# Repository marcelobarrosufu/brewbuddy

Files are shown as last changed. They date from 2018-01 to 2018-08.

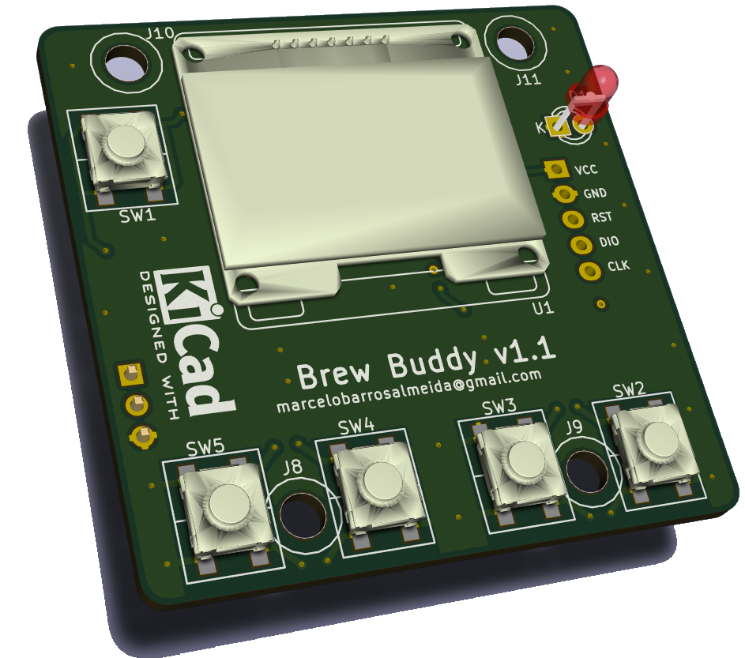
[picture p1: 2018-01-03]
brew_buddy_hardware/docs/f1.png

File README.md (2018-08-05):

# Description

BrewBuddy is a compact device for helping homebrewers in their exhausting task of converting malts, hops and yeasts into happiness.

It can be used as a simple thermometer, like any other analog thermometer found in the market but aggregating time control via stopwatch. As you know, time and temperature walk together when brewing a nice beer.

Although BrewBuddy is not a controller, you can program your recipe using a step mash strategy. BrewBuddy will blink a led when an step is finished, indicating that you can heat the mosture again.

When boiling, it is very easy to program your hop additions, waiting for a BrewBuddy indication. Smartphones or additional devices are not required anymore!

BrewBuddy is powered by a regular CR2032 battery, running for 20h! Menus and configurations are simple and intuitive, you will learn all function in minutes.

You can program up to 10 steps/hop additions (time) and the last setup is automatically saved in non volatile memory.

Some videos:

 - https://youtu.be/tlFAVe8KUfs
 - https://youtu.be/ZO_FSPlZCxY
 - https://youtu.be/FMSUGOILIN4
 - https://youtu.be/00Js_LpAEr8
 - https://youtu.be/yrWA2lQHpJ8

# Author

BrewBuddy was created from scracth by me, Marcelo Barros. I am an electrical engineer, professor and home brewer. After some bad experiences with uncalibrated analog thermometers I decided to create my own thermometer, agregating additional functionalities for mashing and boiling.

# Help Required

If you are a 3D expert and wanna help, please contact me. In the next week my new PCBs will arrive and I can ship  a complete and working board for those that want to develop or improve the current case.

# Compiling

 - Create a new workspace using System Worbenck for STM32 (SW4STM32). For instance,  <path>/brewbuddy
 - Go to brewbuddy directory and clone this repository
 - Starts SW4STM32 and import the project:   File->Import->General->Existing Projects into Workspace
 - In the dialog, please set:
    - Select root directory:  select your workspace directory, <path>/brewbuddy
    - Select the brew buddy project
    - Do not check the option "copy projects into workspace"
 - Before compiling, check optimization as "Optimize for Size (-Os)", under Properties->C/C++ Build->Tool Settings->MCU GCC Compiler->Optimization

# Firmware Notes

BrewBuddy firmware was built with low power requirements in mind, generating several actions:

 - The controller clock was reduced to 1MHz. Internal 8MHz clock (HSI) is used and PLL is disabled. 
 - I2C clock is only 100kHz (standard mode).
 - The main loop (see `main.c`) is only a _WFI (wake for interrupt) call, all code runs in interrupt mode:
   - Systick (1ms) timer is used to coordenate the periodic events (leds, display updates, ADC samplig and calibration). When some action is required, for instance a display update, it creates an event and sets SVD exception as pending. SVD is configured as a low priority exception, running only when other high priority interrupts are idle. This way we can ensure a better temporization for BrewBuddy.
  - Led modes were implemented as the amount of systick ticks for ON and OFF states. Using this strategy, the led processing is very light, taking few CPU time and energy.
  - Floating point is not used (less power and less flash requirements).
  
Some firmware notes:

  - As the battery voltage level is always falling I decided to calibrate the ADC periodically. DMA was not used to sampling the ADC values due the high cost in terms of flash usage. STM32 HAL takes some kBs of flash for DMA and a baremetal usage of DMA is required if we want to keep the flash usage low as possible. I need more time for this implementation. Or I need to use a microcontroller with bigger flash.
  - `bb_scr.c` is the main file for OLED screens. OLED screens are a machine state, in fact. Each screen is represented by a function (state) with the prototype `bb_scr_list_t bb_screen_function(bool first_time, bb_key_event_t *key)`, where:
    - `first_time`: it is used to indicate when we have a new screen to be presented or the same screen. Static text may be drawn in display using this flag, decreasing the amount of elements that need to be updated at each screen refresh.
    - `key`: if a key was pressed the information is here.
    - Remember: screens are implemented as a machine state (function based). So, you must return the next state when leaving the screen function. The list of states is given by the enumeration `bb_scr_list_t`. To include a new state, you must edit the macro `XMACRO_SCR_LIST`, adding a new state ID and a new function name, like `X(BB_SCR_NEW_OP_ID, bb_scr_new_op_boil)`. After, create a function for `bb_scr_new_op_boil` and implement the screen and your state changes based on the screen ID and keys pressed.
  - Step control is implemented in `ctrl.c`. Again, it is a machine state called at each 1s (see `ctrl_sm_run_1s()`). Given a proper initialization, steps can be followed by the states implemented in `ctrl.c`. 
  - All LMT86 handling was implemented in `lmt86.c`. Given the current temperature value (in ADC steps) and the amount of steps for a 2.5V reference, the real temperature (in degrees) is calculate (see `lmt86_conv_temp_1d()`). As we do not use floating point, conversion is based on a mV x degrees table (provided by datasheet). A simple interpolation is performed when the current value is not in the table. The temperature value is multiplied by ten for a minimum precision in integer operations.
  - If you want to change fonts, check the file `ssd1306_fonts.c`. We are using a small 7x5 font due to flash limits but it is possible to create bigger fonts and better presentation. The SSD1306 driver is minimal as well, a stripped/modified version of original driver provided by stm32f4-discovery.net. 
  - In `persist.c` you can find the default value for persistence and the routines to save / restore values from flash. A CRC is provided to check data integrity. The last flash sector (1kB) is used for data storage.
  
  At this moment, we do not have flash for anything else, even compiling for release and using size optimization:

| Flash | RAM (data+bss) |
| --- | --- |
| 15092 of 15360 bytes (98.3%) | 1200 of 4096 bytes (29.3%) |

# Adding localization support 

Some steps to add support for a new language:

  - Create a copy of `bb_locale_ENUS.h` and modify the suffix using a combination of [ISO-639 Language Codes and ISO ISO-3166 Country Codes](https://docs.oracle.com/cd/E13214_01/wli/docs92/xref/xqisocodes.html). For instance, you can use `bb_locale_ESCL.h` for Spanish and Chile.
  - Change the define `BB_DEFAULT_LOCALE` inside `bb_locale.h` (use your localization file name).
  - Translate the file contents. 
  - In special, for units, change `BB_TEMP_UNIT_IS_CELSIUS` and `BB_TEMP_UNIT_LABEL` for your corresponding temperature unit (0 and 'F' for Fahrenheit and 1 and 'C' for Celsius).

# CAD Files

Please, install KiCAD for opening schematics and PCB.

# TODO

 - When followings steps, make possible to go to next step without waiting the heating phase (just pressing RIGHT key)
 - Calibration menu
 - Setup menu, for temperatue and language
 - Change the microcontroller for more flash space (required for additional menus). STM32F030K6 or STM32F031F6 are possible options. The second one is more expensive but pin compatible.
 - Read internal temperature (for protection or calibration).
 - Low battery indication at startup.

# Licensing

BrewBuddy by Marcelo Barros de Almeida is licensed under a Creative Commons Attribution-NonCommercial-ShareAlike 4.0 International License.
If you want to create a commercial device based on BrewBuddy, please contact me for other licenses and prices.

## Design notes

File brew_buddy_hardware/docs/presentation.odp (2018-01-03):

## BrewBuddy: Overview

Author : Marcelo Barros de Almeida

Email : marcelobarrosalmeida@gmail.com

Project: https://hackaday.io/project/28667-brewbuddy

Code : https://github.com/marcelobarrosalmeida/brewbuddy

## BrewBuddy: Thermometer

Author : Marcelo Barros de Almeida

Email : marcelobarrosalmeida@gmail.com

Project: https://hackaday.io/project/28667-brewbuddy

Code : https://github.com/marcelobarrosalmeida/brewbuddy

## BrewBuddy: Moisture

Author : Marcelo Barros de Almeida

Email : marcelobarrosalmeida@gmail.com

Project: https://hackaday.io/project/28667-brewbuddy

Code : https://github.com/marcelobarrosalmeida/brewbuddy

## BrewBuddy: Boiling/Hoping

Author : Marcelo Barros de Almeida

Email : marcelobarrosalmeida@gmail.com

Project: https://hackaday.io/project/28667-brewbuddy

Code : https://github.com/marcelobarrosalmeida/brewbuddy

## What is BrewBuddy ?

  BrewBuddy is a compact device for helping homebrewers in their exhausting task of converting malts, hops and yeasts into happiness !

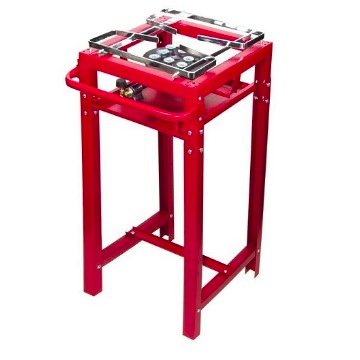
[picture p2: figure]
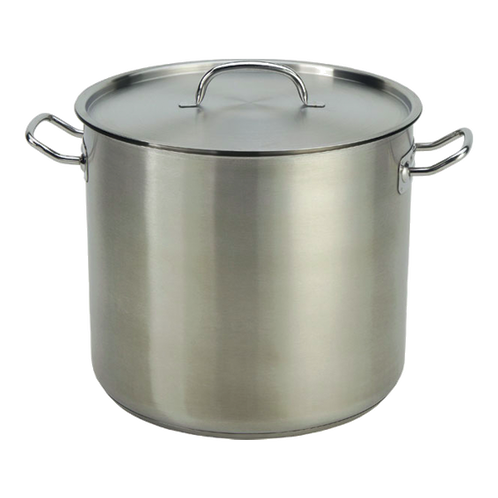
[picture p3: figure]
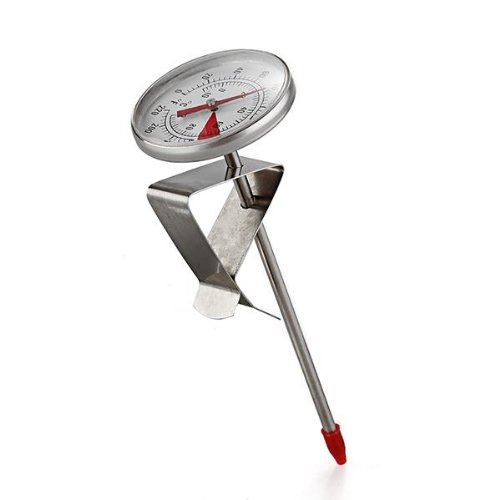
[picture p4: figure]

## BrewBuddy Functions

  - Thermometer: like an analog thermometer but aggregating time control via stopwatches (progressive and regressive).
  - Step mash: You can program your temperature steps and duration when mashing. BrewBuddy will blink a led when an step is finished.
  - Hop additions: When boiling, it is very easy to program your hop additions. Again, BrewBuddy will indicate when it occurs.

## BrewBuddy Functions

  - You can program up to ten mesh steps and ten hop additions.
  - Your last setup is automatically saved in non volatile memory.
  - BrewBuddy is powered by a CR2032 battery, working up to 20 hours.
  - Menus and configurations are simple and intuitive, you will learn all function in minutes.

## Main Components

  - Microcontrolled PCB using a low cost STM32F030F4
  - OLED Display 128x64
  - LMT86 analog temperature sensor
  - ADR5041BRTZ voltage reference (2.5V)
  - Stainless steel tube for temperature measurement
  - 3D housing under development

## BrewBuddy Navigation

On/off in a

single button

Indication

led

UP button

RIGHT button

DOWN button

LEFT button

## BrewBuddy Menu

BrewBuddy

starts here !

BOILING

Boiling programming (temperature and duration).

Hop additions programming (duration).

Boiling/hops follow up.

MOISTURE

Step programming (temperature and duration).

Steps follow up.

THERMOMETER

Temperature follow up and time measurements

## Demonstration Video

  For faster demonstration, usual timer (whose unit is minute) was replaced by a timer in seconds. Moreover, temperatures were simulated.
  ►Demonstration mode: turn BrewBuddy on with LEFT button pressed
  ►Factory init mode: turn BrewBuddy on with RIGHT button pressed


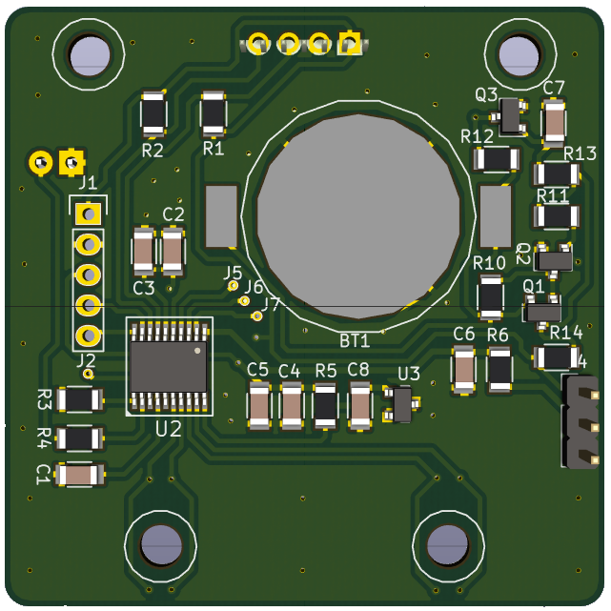
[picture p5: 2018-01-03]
brew_buddy_hardware/docs/f3.png

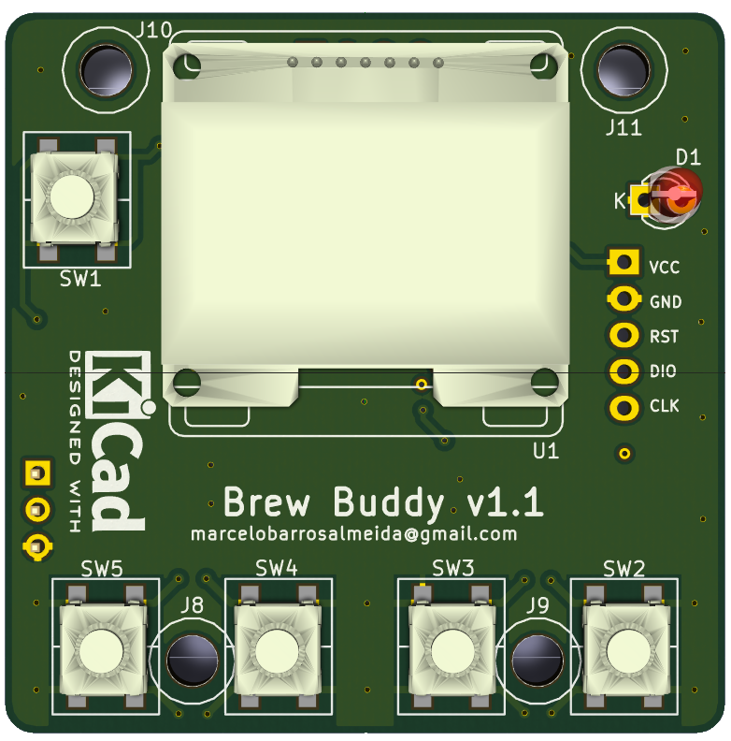
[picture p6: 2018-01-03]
brew_buddy_hardware/docs/f2.png

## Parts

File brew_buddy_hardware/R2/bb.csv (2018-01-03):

Source | /home/marcelo/Desktop/dados/bitbucket/beer_buddy_workspace/brew_buddy_hardware/R2/bb.sch
Kicad Rev | Eeschema 4.0.2+dfsg1-stable
Generated Date | Sex 29 Dez 2017 09:19:51 -02
Title | Beer Buddy
Company | Not Set
Revision | V1
Date Issue | 2017-10-16
Comment | All rights reserved
Comment | marcelobarrosalmeida@gmail.com
Comment | Marcelo Barros de Almeida
Reference | Value | Library | Library Ref
U2 | STM32F030F4 | bb | STM32F030F4
SW3 | SW_SPST | switches | SW_SPST
SW4 | SW_SPST | switches | SW_SPST
SW5 | SW_SPST | switches | SW_SPST
SW2 | SW_SPST | switches | SW_SPST
U1 | OLED-DISPLAY-I2C-128X64 | bb | OLED-DISPLAY-I2C-128X64
BT1 | CR2032 | device | Battery_Cell
J4 | Sensor | conn | Conn_01x03
C2 | 100nF | device | C_Small
C3 | 4.7uF | device | C_Small
C5 | 1uF | device | C_Small
R6 | 2K | device | R
R2 | 2K | device | R
R1 | 2K | device | R
C6 | 1uF | device | C_Small
R3 | 10K | device | R
R5 | 3K | device | R
C4 | 10nF | device | C_Small
D1 | LED | device | LED
R4 | 330R | device | R
J1 | JTAG | conn | Conn_01x05
C1 | 100nF | device | C_Small
J5 | PA7 | conn | Conn_01x01
J6 | PA6 | conn | Conn_01x01
J7 | PA5 | conn | Conn_01x01
J2 | PF1 | conn | Conn_01x01
U3 | ADR5041BRTZ | bb | ADR5041BRTZ
Q1 | PMV48XP (PMOS_GSD) | device | Q_PMOS_GSD
Q2 | PMV65UNER (NMOS_GSD) | device | Q_NMOS_GSD
Q3 | PMV65UNER (NMOS_GSD) | device | Q_NMOS_GSD
R10 | 100K | device | R
R11 | 100K | device | R
R13 | 1M | device | R
R12 | 100K | device | R
SW1 | SW_SPST | switches | SW_SPST
C7 | 470nF | device | C_Small
J8 | Drill | conn | Conn_01x01
J9 | Drill | conn | Conn_01x01
J10 | Drill | conn | Conn_01x01
J11 | Drill | conn | Conn_01x01
R14 | 0R | device | R
C8 | 100nF | device | C_Small

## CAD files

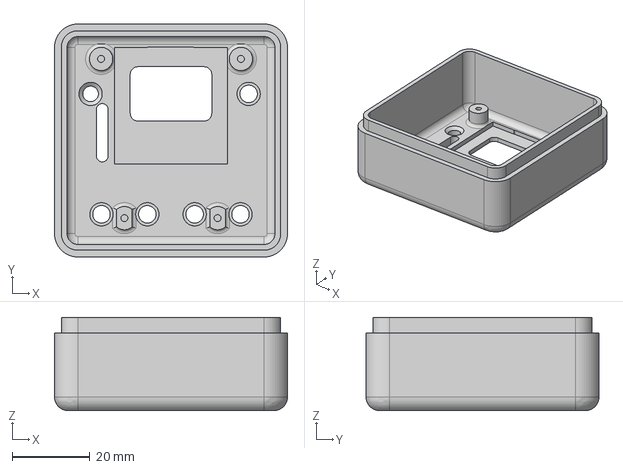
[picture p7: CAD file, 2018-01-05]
brew_buddy_case/Temp_Box_Front_New.step
60.0 x 60.0 x 24.0 mm

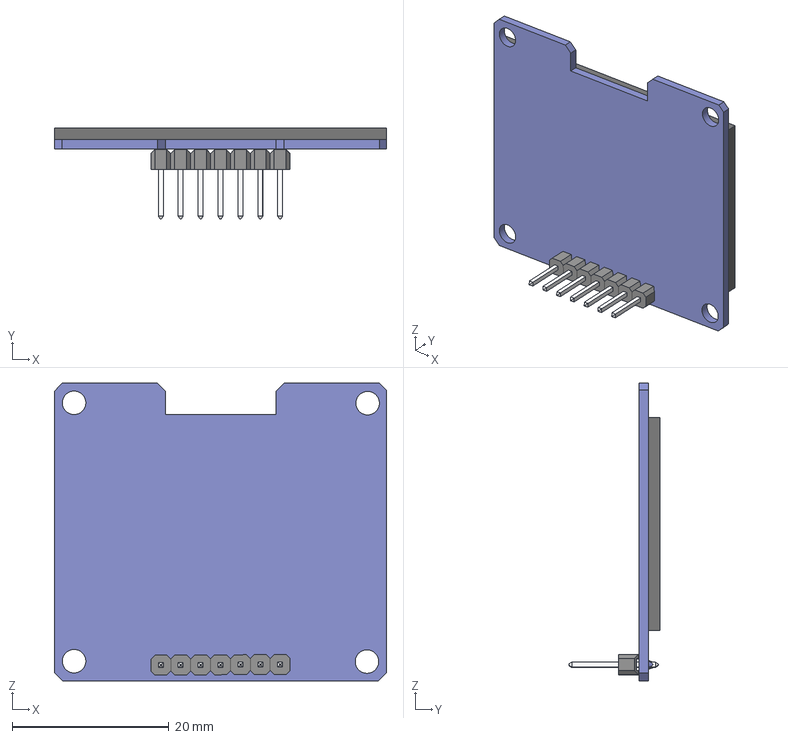
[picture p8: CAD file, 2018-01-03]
brew_buddy_hardware/3d/OLED Display 1.stp
42.4 x 11.7 x 38.0 mm

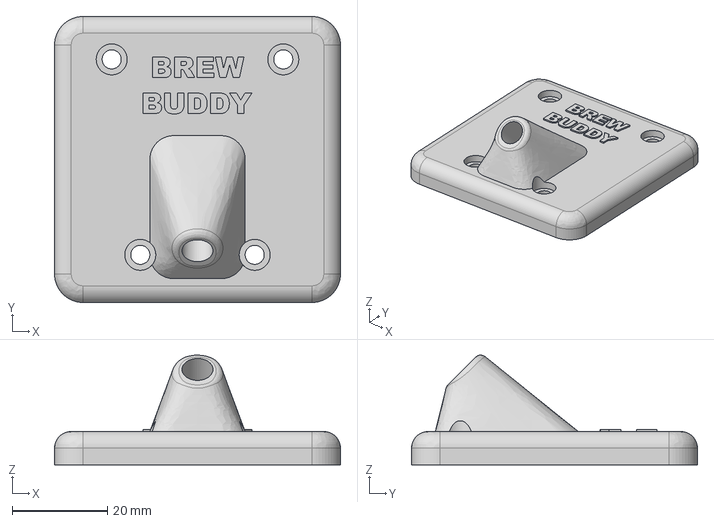
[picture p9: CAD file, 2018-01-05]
brew_buddy_case/Temp_Box_Back_New.step
60.0 x 60.0 x 23.0 mm

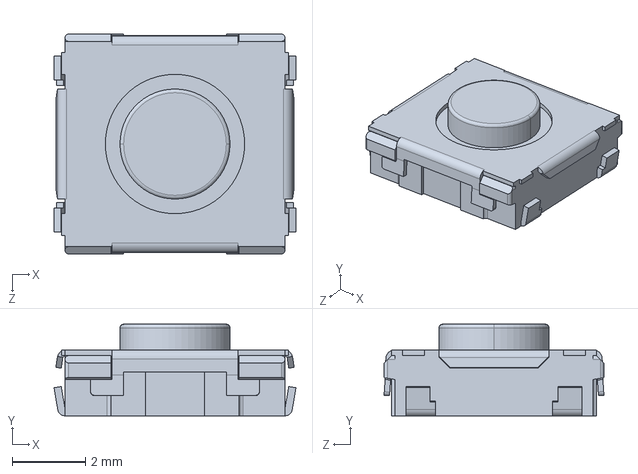
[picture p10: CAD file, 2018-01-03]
brew_buddy_hardware/3d/EVQQ2-BFKPUY-02W.STEP
6.60 x 2.50 x 6.00 mm

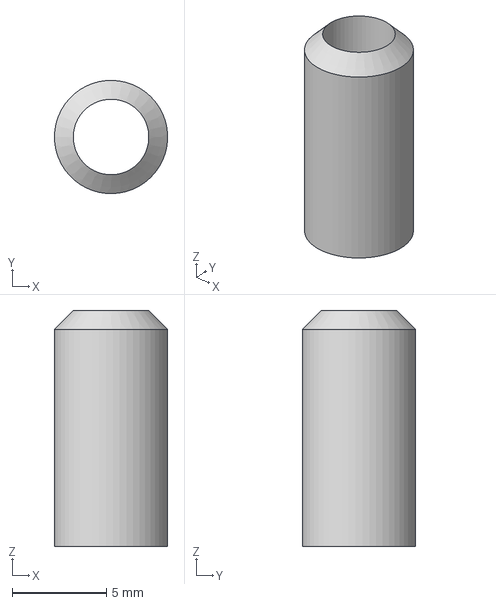
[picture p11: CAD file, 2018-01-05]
brew_buddy_case/Standoff_6X13.step
5.99 x 6.00 x 12.5 mm

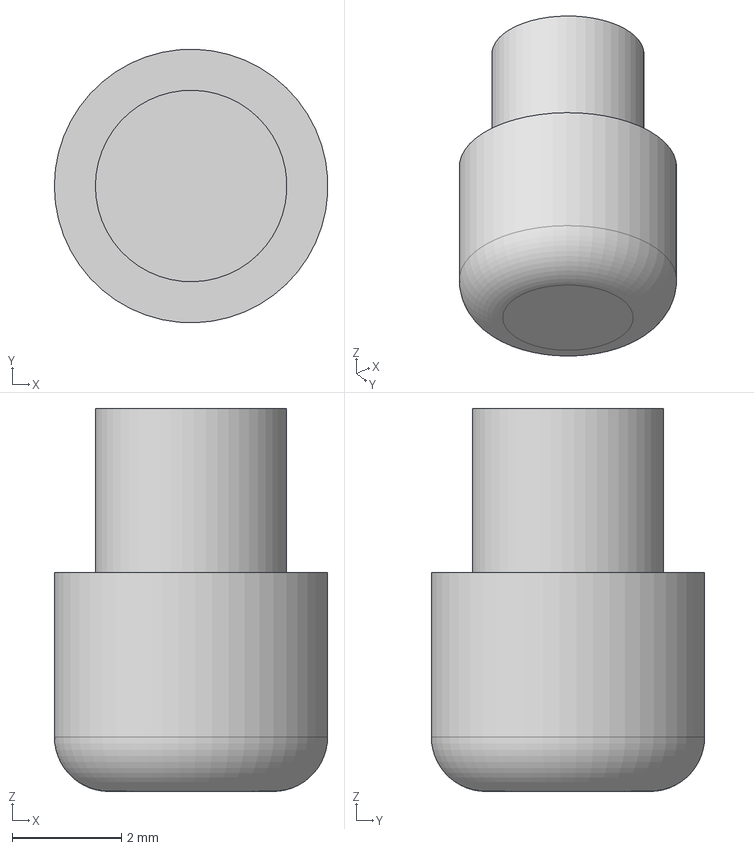
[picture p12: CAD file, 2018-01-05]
brew_buddy_case/Temp_Buttom_New.step
5.00 x 5.00 x 7.00 mm

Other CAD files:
brew_buddy_hardware/3d/OLED Display 2.stl
brew_buddy_case/Standoff_6X13.f3d
brew_buddy_case/Temp_Box_Back_New.f3d
brew_buddy_case/Temp_Box_Front_New.f3d
brew_buddy_case/Temp_Buttom_New.f3d
brew_buddy_hardware/3d/EVQQ2-BFKPUY-02W.stl
brew_buddy_hardware/3d/OLED Display 1.stl

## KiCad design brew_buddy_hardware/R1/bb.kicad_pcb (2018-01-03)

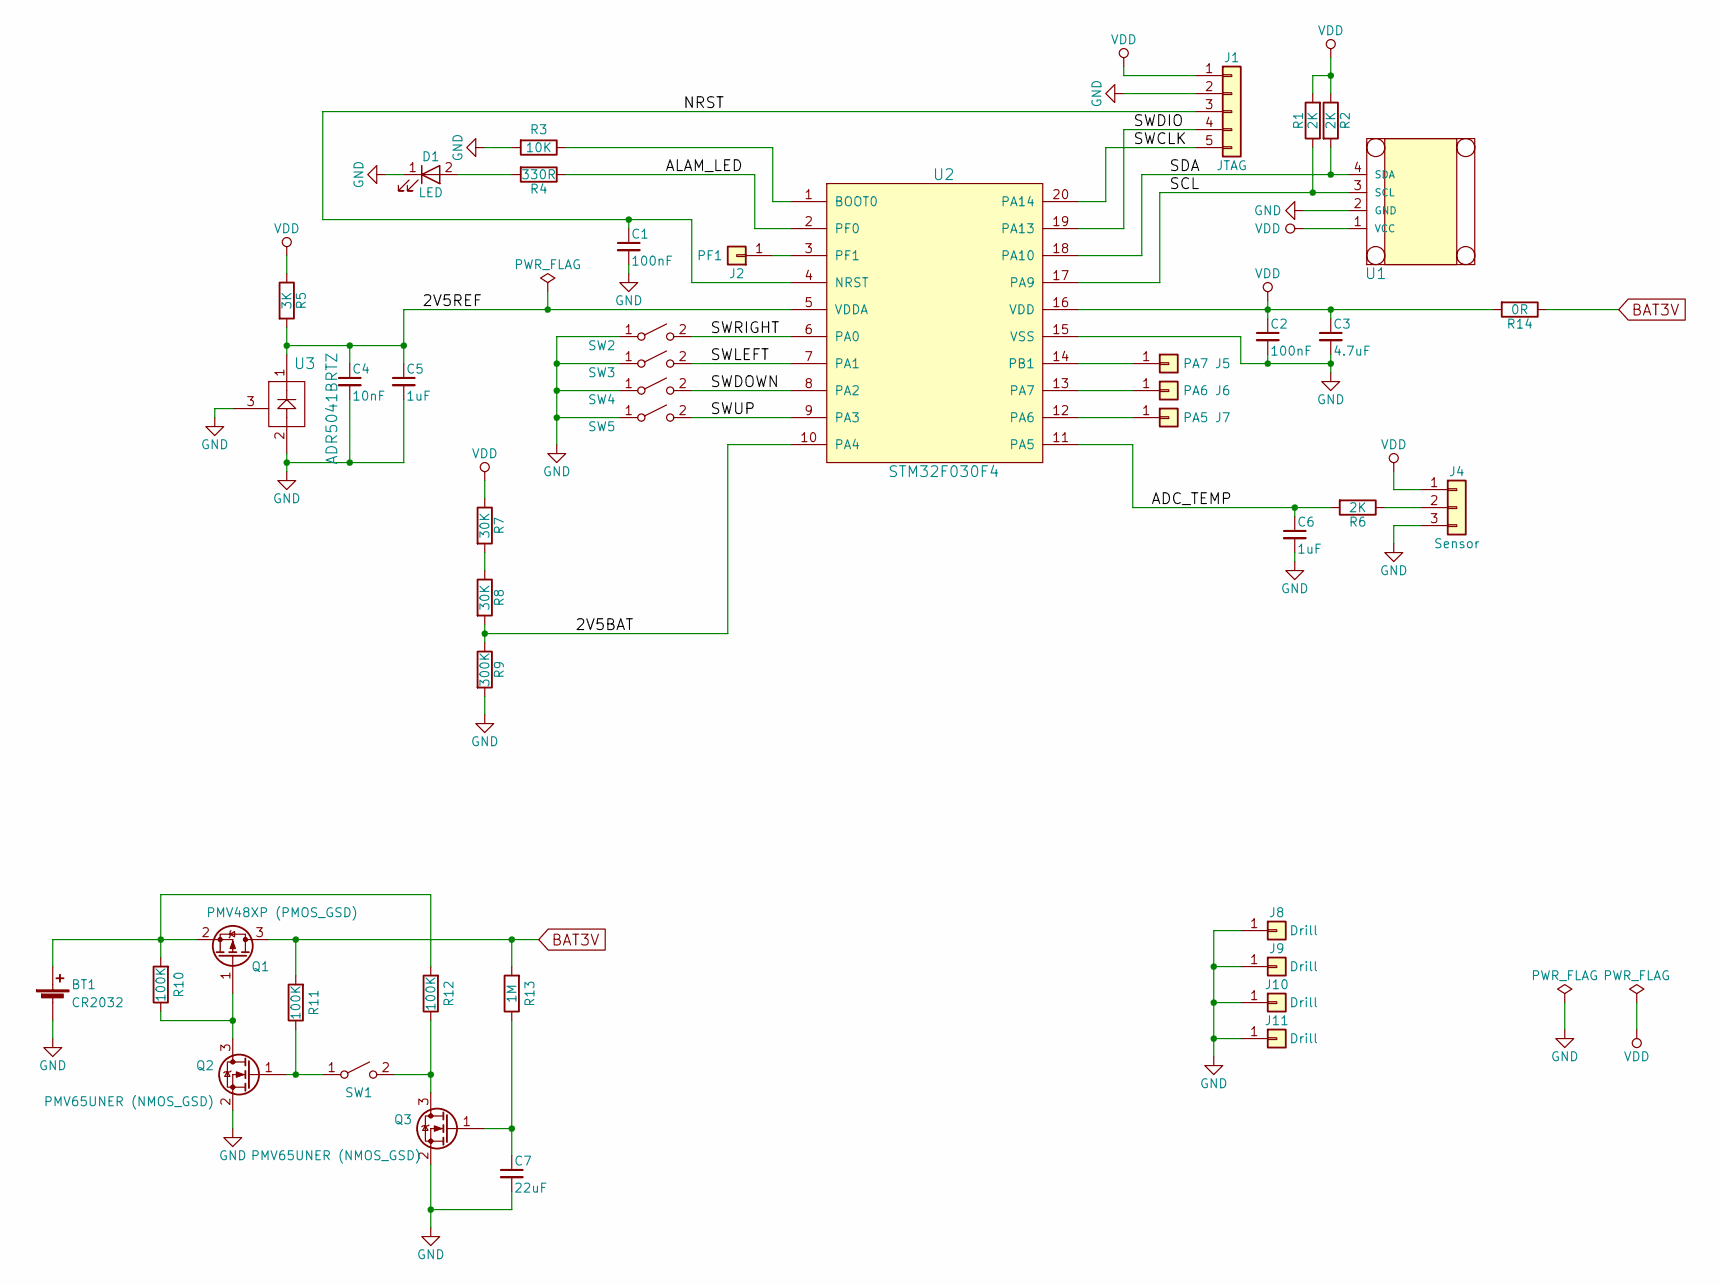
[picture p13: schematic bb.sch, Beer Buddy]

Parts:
BT1: CR2032; BAT-HLD-001-THM
C1, C2: 100nF; C_1206_CUSTOM
C3: 4.7uF; C_1206_CUSTOM
C4: 10nF; C_1206_CUSTOM
C5, C6: 1uF; C_1206_CUSTOM
C7: 22uF; C_1206_CUSTOM
D1: LED; LED-3MM
J1: JTAG; Pin_Header_Straight_1x05
J2: PF1; TEST-PIN
J4: Sensor; Pin_Header_Straight_1x03_Pitch2.54mm
J5: PA7; TEST-PIN
J6: PA6; TEST-PIN
J7: PA5; TEST-PIN
J8, J9, J10, J11: Drill; M3_Connector
Q1: PMV48XP (PMOS_GSD); SOT-23
Q2, Q3: PMV65UNER (NMOS_GSD); SOT-23
R1, R2, R6: 2K; R_1206_CUSTOM
R3: 10K; R_1206_CUSTOM
R4: 330R; R_1206_CUSTOM
R5: 3K; R_1206_CUSTOM
R7, R8: 30K; R_1206_CUSTOM
R9: 300K; R_1206_CUSTOM
R10, R11, R12: 100K; R_1206_CUSTOM
R13: 1M; R_1206_CUSTOM
R14: 0R; R_1206_CUSTOM
SW1, SW2, SW3, SW4, SW5: SW_SPST; EVQ-Q2B02W
U1: OLED-DISPLAY-I2C-128X64; DISPLAY-OLED
U2: STM32F030F4; TSOP-20-STM32F030F4
U3: ADR5041BRTZ; SOT-23

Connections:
/2V5BAT: R8.2, R9.1, U2.10 (PA4)
/2V5REF: C4.1, C5.1, R5.2, U2.5 (VDDA), U3.1
/ADC_TEMP: C6.1, R6.2, U2.11 (PA5)
/ALAM_LED: R4.1, U2.2 (PF0)
/NRST: C1.1, J1.3, U2.4 (NRST)
/SCL: R1.1, U1.3 (SCL), U2.17 (PA9)
/SDA: R2.2, U1.4 (SDA), U2.18 (PA10)
/SWCLK: J1.5, U2.20 (PA14)
/SWDIO: J1.4, U2.19 (PA13)
/SWDOWN: SW4.2 (B), U2.8 (PA2)
/SWLEFT: SW3.2 (B), U2.7 (PA1)
/SWRIGHT: SW2.2 (B), U2.6 (PA0)
/SWUP: SW5.2 (B), U2.9 (PA3)
BAT3V: Q1.3 (D), R11.2, R13.2, R14.1
GND: BT1.2 (-), C1.2, C2.2, C3.2, C4.2, C5.2, C6.2, C7.2, D1.1 (K), J1.2, J4.3, J8.1, J9.1, J10.1, J11.1, Q2.2 (S), Q3.2 (S), R3.2, R9.2, SW2.1 (A), SW3.1 (A), SW4.1 (A), SW5.1 (A), U1.2 (GND), U2.15 (VSS), U3.2, U3.3
unnamed: BT1.1 (+), Q1.2 (S), R10.2, R12.2
unnamed: C7.1, Q3.1 (G), R13.1
unnamed: D1.2 (A), R4.2
unnamed: J2.1, U2.3 (PF1)
unnamed: J4.2, R6.1
unnamed: J5.1, U2.14 (PB1)
unnamed: J6.1, U2.13 (PA7)
unnamed: J7.1, U2.12 (PA6)
unnamed: Q1.1 (G), Q2.3 (D), R10.1
unnamed: Q2.1 (G), R11.1, SW1.1 (A)
unnamed: Q3.3 (D), R12.1, SW1.2 (B)
unnamed: R3.1, U2.1 (BOOT0)
unnamed: R7.2, R8.1
VDD: C2.1, C3.1, J1.1, J4.1, R1.2, R2.1, R5.1, R7.1, R14.2, U1.1 (VCC), U2.16 (VDD)

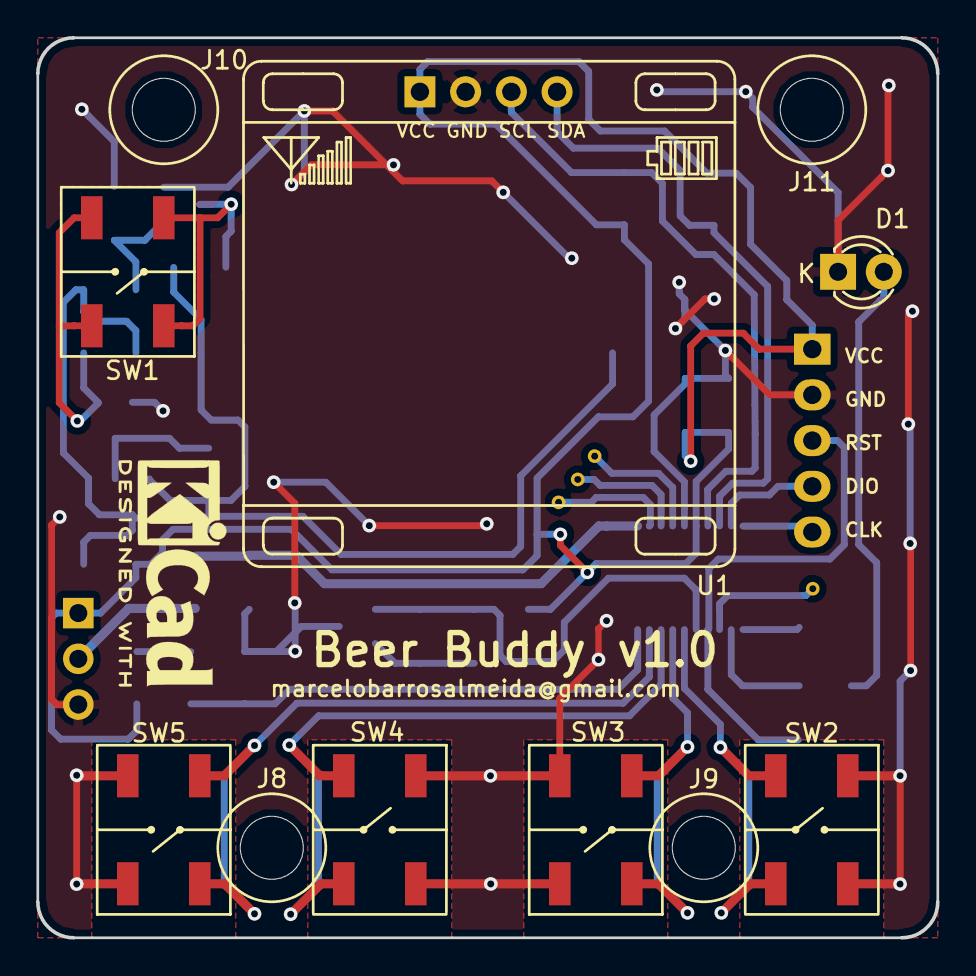
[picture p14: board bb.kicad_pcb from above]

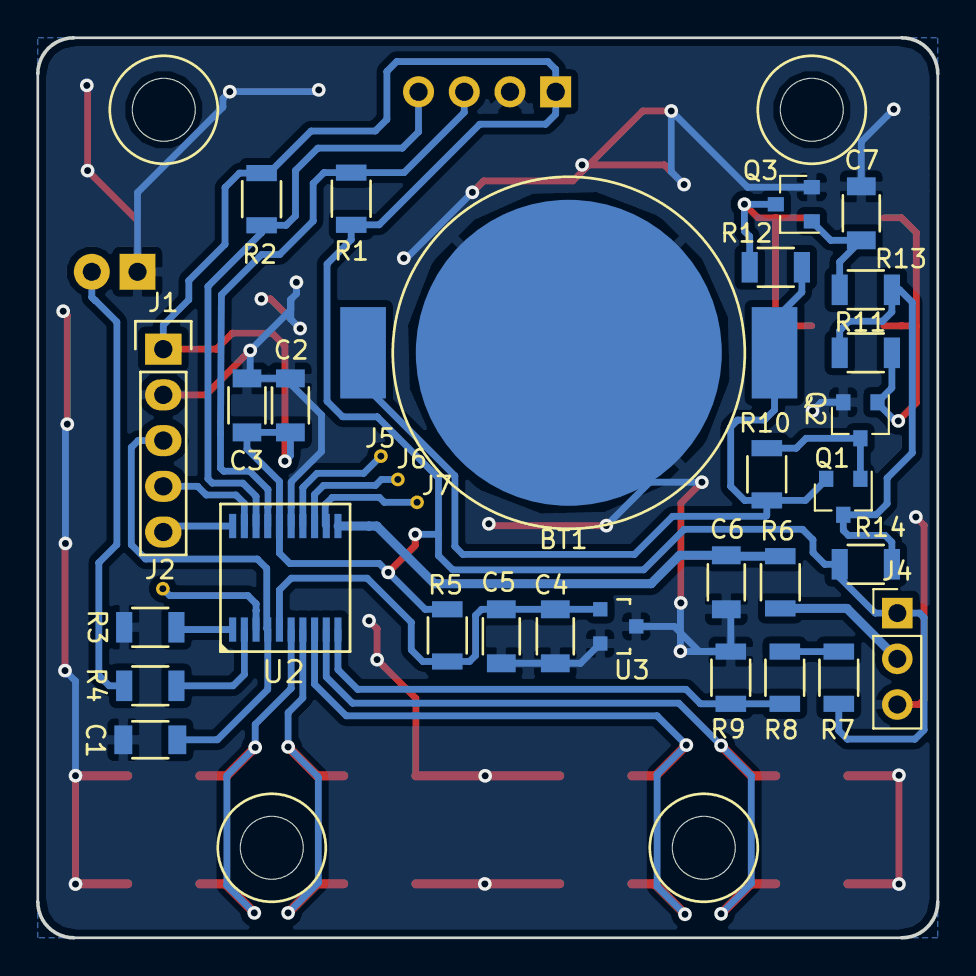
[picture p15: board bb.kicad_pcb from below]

Board: 2 copper layers, 50.0 x 50.0 mm, 44 parts (33 on the bottom side), 29 nets.

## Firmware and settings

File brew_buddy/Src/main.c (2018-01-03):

/*
  BrewBuddy by Marcelo Barros de Almeida is licensed under a
  Creative Commons Attribution-NonCommercial-ShareAlike 4.0 International License.

  For commercial usage, please contact the author via marcelobarrosalmeida@gmail.com
*/

/**
  ******************************************************************************
  * File Name          : main.c
  * Description        : Main program body
  ******************************************************************************
  ** This notice applies to any and all portions of this file
  * that are not between comment pairs USER CODE BEGIN and
  * USER CODE END. Other portions of this file, whether 
  * inserted by the user or by software development tools
  * are owned by their respective copyright owners.
  *
  * COPYRIGHT(c) 2017 STMicroelectronics
  *
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
  ******************************************************************************
  */

/* Includes ------------------------------------------------------------------*/
#include "main.h"
#include "stm32f0xx_hal.h"

/* USER CODE BEGIN Includes */
#include <stdbool.h>
#include <stdint.h>
#include "bb.h"
/* USER CODE END Includes */

ADC_HandleTypeDef hadc;

CRC_HandleTypeDef hcrc;

I2C_HandleTypeDef hi2c1;

IWDG_HandleTypeDef hiwdg;

/* USER CODE BEGIN PV */

/* USER CODE END PV */

void SystemClock_Config(void);
static void MX_GPIO_Init(void);
static void MX_I2C1_Init(void);
static void MX_ADC_Init(void);
static void MX_CRC_Init(void);
static void MX_IWDG_Init(void);

/* USER CODE BEGIN PFP */

/* USER CODE END PFP */

/* USER CODE BEGIN 0 */
void SystemClock_Config_Custom(void)
{
  uint32_t tickstart;

  __HAL_RCC_HSI_CALIBRATIONVALUE_ADJUST(16);
  __HAL_RCC_HSI14ADC_DISABLE();
  __HAL_RCC_HSI14_ENABLE();

  tickstart = HAL_GetTick();
  while(__HAL_RCC_GET_FLAG(RCC_FLAG_HSI14RDY) == RESET)
  {
    if((HAL_GetTick() - tickstart) > HSI14_TIMEOUT_VALUE)
      break;
  }

  __HAL_RCC_HSI14_CALIBRATIONVALUE_ADJUST(16);
  MODIFY_REG(RCC->CFGR, RCC_CFGR_HPRE, RCC_SYSCLK_DIV8);

  __HAL_RCC_SYSCLK_CONFIG(RCC_SYSCLKSOURCE_HSI);

  /* Get Start Tick */
  tickstart = HAL_GetTick();

  while (__HAL_RCC_GET_SYSCLK_SOURCE() != RCC_SYSCLKSOURCE_STATUS_HSI)
  {
    if((HAL_GetTick() - tickstart ) > CLOCKSWITCH_TIMEOUT_VALUE)
      break;
  }

  MODIFY_REG(RCC->CFGR, RCC_CFGR_PPRE, RCC_HCLK_DIV1);
  SystemCoreClock = HAL_RCC_GetSysClockFreq() >> AHBPrescTable[(RCC->CFGR & RCC_CFGR_HPRE)>> RCC_CFGR_HPRE_BITNUMBER];

  HAL_InitTick (TICK_INT_PRIORITY);

  __HAL_RCC_I2C1_CONFIG(RCC_I2C1CLKSOURCE_HSI);

    /**Configure the Systick interrupt time
    */
  HAL_SYSTICK_Config(HAL_RCC_GetHCLKFreq()/1000);

    /**Configure the Systick
    */
  HAL_SYSTICK_CLKSourceConfig(SYSTICK_CLKSOURCE_HCLK);

  /* SysTick_IRQn interrupt configuration */
  HAL_NVIC_SetPriority(SysTick_IRQn, 0, 0);
}

/* USER CODE END 0 */

int main(void)
{

  /* MCU Configuration----------------------------------------------------------*/

  /* Reset of all peripherals, Initializes the Flash interface and the Systick. */
  HAL_Init();

  /* USER CODE BEGIN Init */
#if 1
  SystemClock_Config_Custom();
#else
  /* USER CODE END Init */

  /* Configure the system clock */
  SystemClock_Config();

  /* USER CODE BEGIN SysInit */
#endif
  /* USER CODE END SysInit */

  /* Initialize all configured peripherals */
  MX_GPIO_Init();
  MX_I2C1_Init();
  MX_ADC_Init();
  MX_CRC_Init();
  MX_IWDG_Init();

  /* USER CODE BEGIN 2 */
  bb_init();
  /* USER CODE END 2 */

  /* Infinite loop */
  /* USER CODE BEGIN WHILE */
  while (1)
  {
	  __WFI();
	  HAL_IWDG_Refresh(&hiwdg);
  /* USER CODE END WHILE */

  /* USER CODE BEGIN 3 */

  }
  /* USER CODE END 3 */

}

/** System Clock Configuration
*/
void SystemClock_Config(void)
{

  RCC_OscInitTypeDef RCC_OscInitStruct;
  RCC_ClkInitTypeDef RCC_ClkInitStruct;
  RCC_PeriphCLKInitTypeDef PeriphClkInit;

    /**Initializes the CPU, AHB and APB busses clocks 
    */
  RCC_OscInitStruct.OscillatorType = RCC_OSCILLATORTYPE_HSI|RCC_OSCILLATORTYPE_HSI14
                              |RCC_OSCILLATORTYPE_LSI;
  RCC_OscInitStruct.HSIState = RCC_HSI_ON;
  RCC_OscInitStruct.HSI14State = RCC_HSI14_ON;
  RCC_OscInitStruct.HSICalibrationValue = 16;
  RCC_OscInitStruct.HSI14CalibrationValue = 16;
  RCC_OscInitStruct.LSIState = RCC_LSI_ON;
  RCC_OscInitStruct.PLL.PLLState = RCC_PLL_NONE;
  if (HAL_RCC_OscConfig(&RCC_OscInitStruct) != HAL_OK)
  {
    _Error_Handler(__FILE__, __LINE__);
  }

    /**Initializes the CPU, AHB and APB busses clocks 
    */
  RCC_ClkInitStruct.ClockType = RCC_CLOCKTYPE_HCLK|RCC_CLOCKTYPE_SYSCLK
                              |RCC_CLOCKTYPE_PCLK1;
  RCC_ClkInitStruct.SYSCLKSource = RCC_SYSCLKSOURCE_HSI;
  RCC_ClkInitStruct.AHBCLKDivider = RCC_SYSCLK_DIV8;
  RCC_ClkInitStruct.APB1CLKDivider = RCC_HCLK_DIV1;

  if (HAL_RCC_ClockConfig(&RCC_ClkInitStruct, FLASH_LATENCY_0) != HAL_OK)
  {
    _Error_Handler(__FILE__, __LINE__);
  }

  PeriphClkInit.PeriphClockSelection = RCC_PERIPHCLK_I2C1;
  PeriphClkInit.I2c1ClockSelection = RCC_I2C1CLKSOURCE_HSI;
  if (HAL_RCCEx_PeriphCLKConfig(&PeriphClkInit) != HAL_OK)
  {
    _Error_Handler(__FILE__, __LINE__);
  }

    /**Configure the Systick interrupt time 
    */
  HAL_SYSTICK_Config(HAL_RCC_GetHCLKFreq()/1000);

    /**Configure the Systick 
    */
  HAL_SYSTICK_CLKSourceConfig(SYSTICK_CLKSOURCE_HCLK);

  /* SysTick_IRQn interrupt configuration */
  HAL_NVIC_SetPriority(SysTick_IRQn, 0, 0);
}

/* ADC init function */
static void MX_ADC_Init(void)
{

  ADC_ChannelConfTypeDef sConfig;

    /**Configure the global features of the ADC (Clock, Resolution, Data Alignment and number of conversion) 
    */
  hadc.Instance = ADC1;
  hadc.Init.ClockPrescaler = ADC_CLOCK_ASYNC_DIV1;
  hadc.Init.Resolution = ADC_RESOLUTION_12B;
  hadc.Init.DataAlign = ADC_DATAALIGN_RIGHT;
  hadc.Init.ScanConvMode = ADC_SCAN_DIRECTION_FORWARD;
  hadc.Init.EOCSelection = ADC_EOC_SINGLE_CONV;
  hadc.Init.LowPowerAutoWait = ENABLE;
  hadc.Init.LowPowerAutoPowerOff = ENABLE;
  hadc.Init.ContinuousConvMode = DISABLE;
  hadc.Init.DiscontinuousConvMode = DISABLE;
  hadc.Init.ExternalTrigConv = ADC_SOFTWARE_START;
  hadc.Init.ExternalTrigConvEdge = ADC_EXTERNALTRIGCONVEDGE_NONE;
  hadc.Init.DMAContinuousRequests = DISABLE;
  hadc.Init.Overrun = ADC_OVR_DATA_PRESERVED;
  if (HAL_ADC_Init(&hadc) != HAL_OK)
  {
    _Error_Handler(__FILE__, __LINE__);
  }

    /**Configure for the selected ADC regular channel to be converted. 
    */
  sConfig.Channel = ADC_CHANNEL_5;
  sConfig.Rank = ADC_RANK_CHANNEL_NUMBER;
  sConfig.SamplingTime = ADC_SAMPLETIME_71CYCLES_5;
  if (HAL_ADC_ConfigChannel(&hadc, &sConfig) != HAL_OK)
  {
    _Error_Handler(__FILE__, __LINE__);
  }

    /**Configure for the selected ADC regular channel to be converted. 
    */
  sConfig.Channel = ADC_CHANNEL_6;
  if (HAL_ADC_ConfigChannel(&hadc, &sConfig) != HAL_OK)
  {
    _Error_Handler(__FILE__, __LINE__);
  }

}

/* CRC init function */
static void MX_CRC_Init(void)
{

  hcrc.Instance = CRC;
  hcrc.Init.DefaultPolynomialUse = DEFAULT_POLYNOMIAL_ENABLE;
  hcrc.Init.DefaultInitValueUse = DEFAULT_INIT_VALUE_ENABLE;
  hcrc.Init.InputDataInversionMode = CRC_INPUTDATA_INVERSION_NONE;
  hcrc.Init.OutputDataInversionMode = CRC_OUTPUTDATA_INVERSION_DISABLE;
  hcrc.InputDataFormat = CRC_INPUTDATA_FORMAT_WORDS;
  if (HAL_CRC_Init(&hcrc) != HAL_OK)
  {
    _Error_Handler(__FILE__, __LINE__);
  }

}

/* I2C1 init function */
static void MX_I2C1_Init(void)
{

  hi2c1.Instance = I2C1;
  hi2c1.Init.Timing = 0x2000090E;
  hi2c1.Init.OwnAddress1 = 0;
  hi2c1.Init.AddressingMode = I2C_ADDRESSINGMODE_7BIT;
  hi2c1.Init.DualAddressMode = I2C_DUALADDRESS_DISABLE;
  hi2c1.Init.OwnAddress2 = 0;
  hi2c1.Init.OwnAddress2Masks = I2C_OA2_NOMASK;
  hi2c1.Init.GeneralCallMode = I2C_GENERALCALL_DISABLE;
  hi2c1.Init.NoStretchMode = I2C_NOSTRETCH_DISABLE;
  if (HAL_I2C_Init(&hi2c1) != HAL_OK)
  {
    _Error_Handler(__FILE__, __LINE__);
  }

    /**Configure Analogue filter 
    */
  if (HAL_I2CEx_ConfigAnalogFilter(&hi2c1, I2C_ANALOGFILTER_ENABLE) != HAL_OK)
  {
    _Error_Handler(__FILE__, __LINE__);
  }

    /**Configure Digital filter 
    */
  if (HAL_I2CEx_ConfigDigitalFilter(&hi2c1, 0) != HAL_OK)
  {
    _Error_Handler(__FILE__, __LINE__);
  }

}

/* IWDG init function */
static void MX_IWDG_Init(void)
{

  hiwdg.Instance = IWDG;
  hiwdg.Init.Prescaler = IWDG_PRESCALER_64;
  hiwdg.Init.Window = 4095;
  hiwdg.Init.Reload = 1875;
  if (HAL_IWDG_Init(&hiwdg) != HAL_OK)
  {
    _Error_Handler(__FILE__, __LINE__);
  }

}

/** Configure pins as 
        * Analog 
        * Input 
        * Output
        * EVENT_OUT
        * EXTI
*/
static void MX_GPIO_Init(void)
{

  GPIO_InitTypeDef GPIO_InitStruct;

  /* GPIO Ports Clock Enable */
  __HAL_RCC_GPIOF_CLK_ENABLE();
  __HAL_RCC_GPIOA_CLK_ENABLE();

  /*Configure GPIO pin Output Level */
  HAL_GPIO_WritePin(GPIOF, GPIO_PIN_0|GPIO_PIN_1, GPIO_PIN_RESET);

  /*Configure GPIO pins : PF0 PF1 */
  GPIO_InitStruct.Pin = GPIO_PIN_0|GPIO_PIN_1;
  GPIO_InitStruct.Mode = GPIO_MODE_OUTPUT_PP;
  GPIO_InitStruct.Pull = GPIO_NOPULL;
  GPIO_InitStruct.Speed = GPIO_SPEED_FREQ_LOW;
  HAL_GPIO_Init(GPIOF, &GPIO_InitStruct);

  /*Configure GPIO pins : PA0 PA1 PA2 PA3 */
  GPIO_InitStruct.Pin = GPIO_PIN_0|GPIO_PIN_1|GPIO_PIN_2|GPIO_PIN_3;
  GPIO_InitStruct.Mode = GPIO_MODE_IT_RISING_FALLING;
  GPIO_InitStruct.Pull = GPIO_PULLUP;
  HAL_GPIO_Init(GPIOA, &GPIO_InitStruct);

  /* EXTI interrupt init*/
  HAL_NVIC_SetPriority(EXTI0_1_IRQn, 1, 0);
  HAL_NVIC_EnableIRQ(EXTI0_1_IRQn);

  HAL_NVIC_SetPriority(EXTI2_3_IRQn, 1, 0);
  HAL_NVIC_EnableIRQ(EXTI2_3_IRQn);

}

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


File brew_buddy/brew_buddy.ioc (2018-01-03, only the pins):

Mcu.UserName=STM32F030F4Px
PA0.Signal=GPXTI0
PA1.Signal=GPXTI1
PA10.Signal=I2C1_SDA
PA13.Signal=SYS_SWDIO
PA14.Signal=SYS_SWCLK
PA2.Signal=GPXTI2
PA3.Signal=GPXTI3
PA5.Signal=ADC_IN5
PA6.Signal=ADC_IN6
PA9.Signal=I2C1_SCL
PF0-OSC_IN.Signal=GPIO_Output
PF1-OSC_OUT.Signal=GPIO_Output

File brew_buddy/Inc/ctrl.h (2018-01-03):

/*
  BrewBuddy by Marcelo Barros de Almeida is licensed under a
  Creative Commons Attribution-NonCommercial-ShareAlike 4.0 International License.

  For commercial usage, please contact the author via marcelobarrosalmeida@gmail.com
*/

#ifndef CTRL_H_
#define CTRL_H_

#define CTRL_MAX_SLOPES 10
#define CTRL_MAX_HOPS   10
#if BB_TEMP_UNIT_IS_CELSIUS == 1
	#define CTRL_MAX_TEMP   105
	#define CTRL_MIN_TEMP   0
#else
	#define CTRL_MAX_TEMP   221
	#define CTRL_MIN_TEMP   32
#endif
#define CTRL_MAX_TIME_S (60*200)

typedef struct ctrl_slope_s
{
	uint16_t time_s;
	uint8_t temp;
} ctrl_slope_t;

typedef struct ctrl_hop_s
{
	uint16_t time_s;
	uint8_t number;
} ctrl_hop_t;

void ctrl_init(void);
void ctrl_sm_run_1s(void);
void ctrl_boil_get(ctrl_slope_t *boil);
void ctrl_boil_set(ctrl_slope_t boil);
void ctrl_slope_get(uint8_t n, ctrl_slope_t *slope);
void ctrl_slope_set(uint8_t n, ctrl_slope_t *slope);
void ctrl_sm_start(uint8_t num_slopes, uint8_t num_hops, bool is_boil);
void ctrl_curr_exec_hop_data_get(uint8_t *num_hops, uint16_t *next_hop_time, uint8_t *hop_list, uint8_t *hop_list_size);
void ctrl_curr_exec_data_get(uint8_t *num_slopes, uint8_t *cur_slope, uint16_t *time_s, ctrl_slope_t *slope_info, bool *heating, bool *paused);
bool ctrl_sm_finished(void);
void ctrl_sm_pause_set(bool paused);
bool ctrl_sm_pause_get(void);
void ctrl_sm_stop(void);
void ctrl_sm_forward(void);
void ctrl_sm_backward(void);
uint8_t ctrl_sm_get_cur_slope(void);
void ctrl_hop_get(uint8_t n, ctrl_hop_t *hop);
void ctrl_hop_set(uint8_t n, ctrl_hop_t *hop);
bool ctrl_sm_waiting_hop(void);
void ctrl_hope_addition_done(void);

#endif /* CTRL_H_ */

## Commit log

2018-01-03 first public version
    [EVQQ2-BFKPUY-02W.STEP, EVQQ2-BFKPUY-02W.stl, OLED Display 1.stl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]
2018-01-05 Adding design files for case
    [Standoff_6X13.f3d, Standoff_6X13.step, Temp_Box_Back_New.f3d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]
2018-08-05 fixing localization support and improving localization documentation
    [bb_locale_ENUS.h, lmt86.c]
2018-08-05 fixing scale conversion bug
    [bb.c]

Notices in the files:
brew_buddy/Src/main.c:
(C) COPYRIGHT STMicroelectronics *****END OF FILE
